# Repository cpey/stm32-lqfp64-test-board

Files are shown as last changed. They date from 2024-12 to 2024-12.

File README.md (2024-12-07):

# STM32 LQFP64 Test Board

A test board designed for STM32 microcontrollers in LQFP64 package. It is intended for use with the STM32F3 and STM32F0 64-pin MCUs, which are mostly pin-to-pin compatbile. The board is programmable via JTAG and SWD using the [STLINK-V3MINIE](https://www.st.com/en/development-tools/stlink-v3minie.html) programmer.

Check out the [schematic](https://github.com/cpey/stm32-lqfp64-test-board/blob/main/stm32_lqfp64_test_board/stm32_lqfp64_test_board.pdf) and the MCU [pin configuration](https://github.com/cpey/stm32-lqfp64-test-board/blob/main/pinout) for more details.

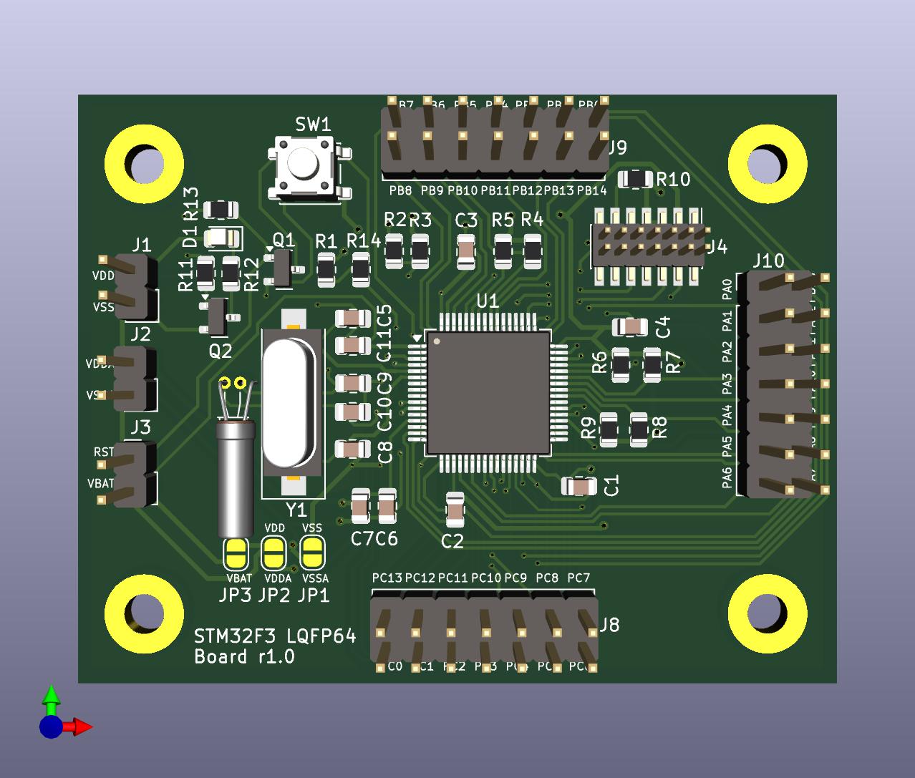
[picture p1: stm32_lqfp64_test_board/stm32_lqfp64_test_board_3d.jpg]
Rendered 3D view of the STM32 LQFP64 test board.


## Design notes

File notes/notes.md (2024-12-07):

# LED resistor calculation

## Collector resistor:

>>> (3.3 - 2) / 20e-3
64.99999999999999

where: 
- 2V is the forward voltage of the LED:
- 20e-3 A is the LED current

## Base resistor:

B -- beta
I_b -- Current base
V_be -- Voltage base-emitter

B = 160
I_b = 20e-3 / 160 = 0.00125 = 1.25 mA 

Voltage Base-Emitter is 0.7V:

R = (3.3 - 0.7) / 1.25e-3 = 2079.9

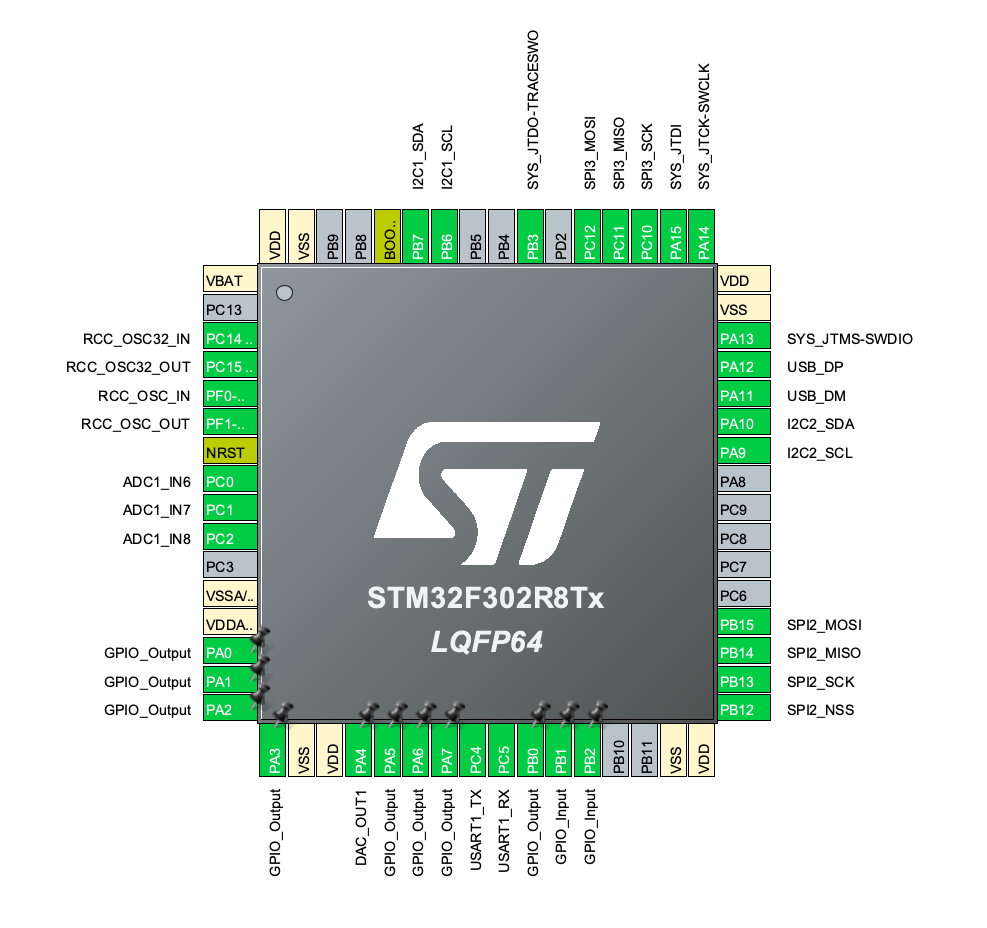
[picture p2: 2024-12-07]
pinout/STM32F302.png

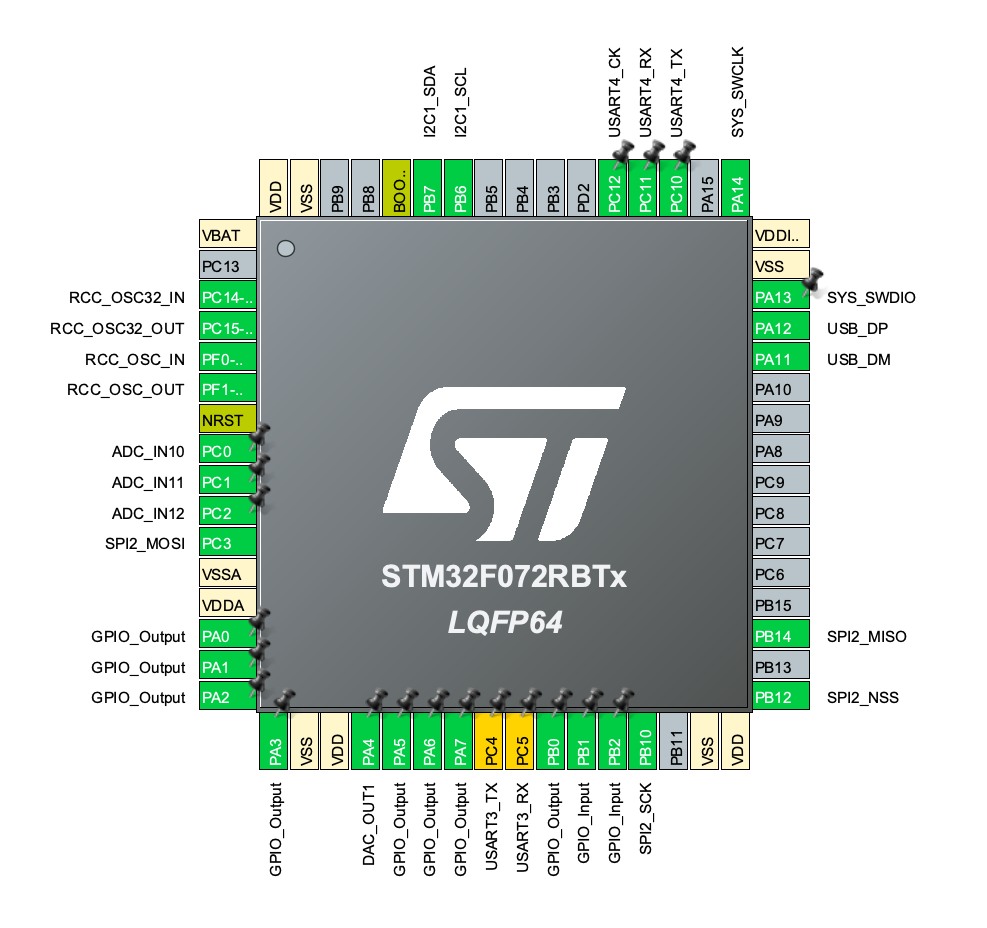
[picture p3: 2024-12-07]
pinout/STM32F072.png

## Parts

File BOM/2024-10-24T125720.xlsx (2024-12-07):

Index | Quantity | Part Number | Manufacturer Part Number | Description | Customer Reference | Available | Backorder | Unit Price | Extended Price USD
1 | 3 | 497-14698-ND | STM32F302R8T6 | IC MCU 32BIT 64KB FLASH 64LQFP |  | 3 | 0 | 6.05 | 18.15
2 | 3 | 497-14644-ND | STM32F072RBT6 | IC MCU 32BIT 128KB FLASH 64LQFP |  | 3 | 0 | 5.72 | 17.16
3 | 3 | 631-1010-1-ND | FC4SDCBMF8.0-T1 | CRYSTAL 8.0000MHZ 20PF SMD |  | 3 | 0 | 0.26 | 0.78
4 | 20 | 478-12776-1-ND | 08055A300JAT2A | CAP CER 30PF 50V C0G/NP0 0805 |  | 20 | 0 | 0.05 | 1.00
5 | 3 | 300-8301-ND | CFS-20632768DZBB | CRYSTAL 32.7680KHZ 6PF TH |  | 3 | 0 | 0.21 | 0.63
6 | 20 | YAG3364CT-ND | RT0805FRE074K7L | RES SMD 4.7K OHM 1% 1/8W 0805 |  | 20 | 0 | 0.03 | 0.60
7 | 20 | 399-C0805C109C5HACAUTOCT-ND | C0805C109C5HACAUTO | CAP CER 0805 1PF 50V ULTRA STABL |  | 20 | 0 | 0.078 | 1.56
8 | 10 | 785-1000-1-ND | AO3400A | MOSFET N-CH 30V 5.7A SOT23-3L |  | 10 | 0 | 0.224 | 2.24
9 | 5 | PTS647SM38SMTR2LFSCT-ND | PTS 647 SM38 SMTR2 LFS | SWITCH TACTILE SPST-NO 0.05A 12V |  | 5 | 0 | 0.26 | 1.30
10 | 20 | RMCF0805FT2K10CT-ND | RMCF0805FT2K10 | RES 2.1K OHM 1% 1/8W 0805 |  | 20 | 0 | 0.021 | 0.42
11 | 10 | 732-4984-1-ND | 150080RS75000 | LED RED CLEAR 0805 SMD |  | 10 | 0 | 0.18 | 1.80
12 | 20 | 311-64.9CRCT-ND | RC0805FR-0764R9L | RES 64.9 OHM 1% 1/8W 0805 |  | 20 | 0 | 0.016 | 0.32
13 | 1 | 497-STLINK-V3MINIE-ND | STLINK-V3MINIE | ST-LINK V3 PROG FOR STM32 |  | 1 | 0 | 11.71 | 11.71
14 | 3 | SAM13170CT-ND | FTSH-107-01-F-DV-K-P-TR | CONN HEADER SMD 14POS 1.27MM |  | 3 | 0 | 2.95 | 8.85
15 | 20 | RMCF0805FT100RCT-ND | RMCF0805FT100R | RES 100 OHM 1% 1/8W 0805 |  | 20 | 0 | 0.021 | 0.42

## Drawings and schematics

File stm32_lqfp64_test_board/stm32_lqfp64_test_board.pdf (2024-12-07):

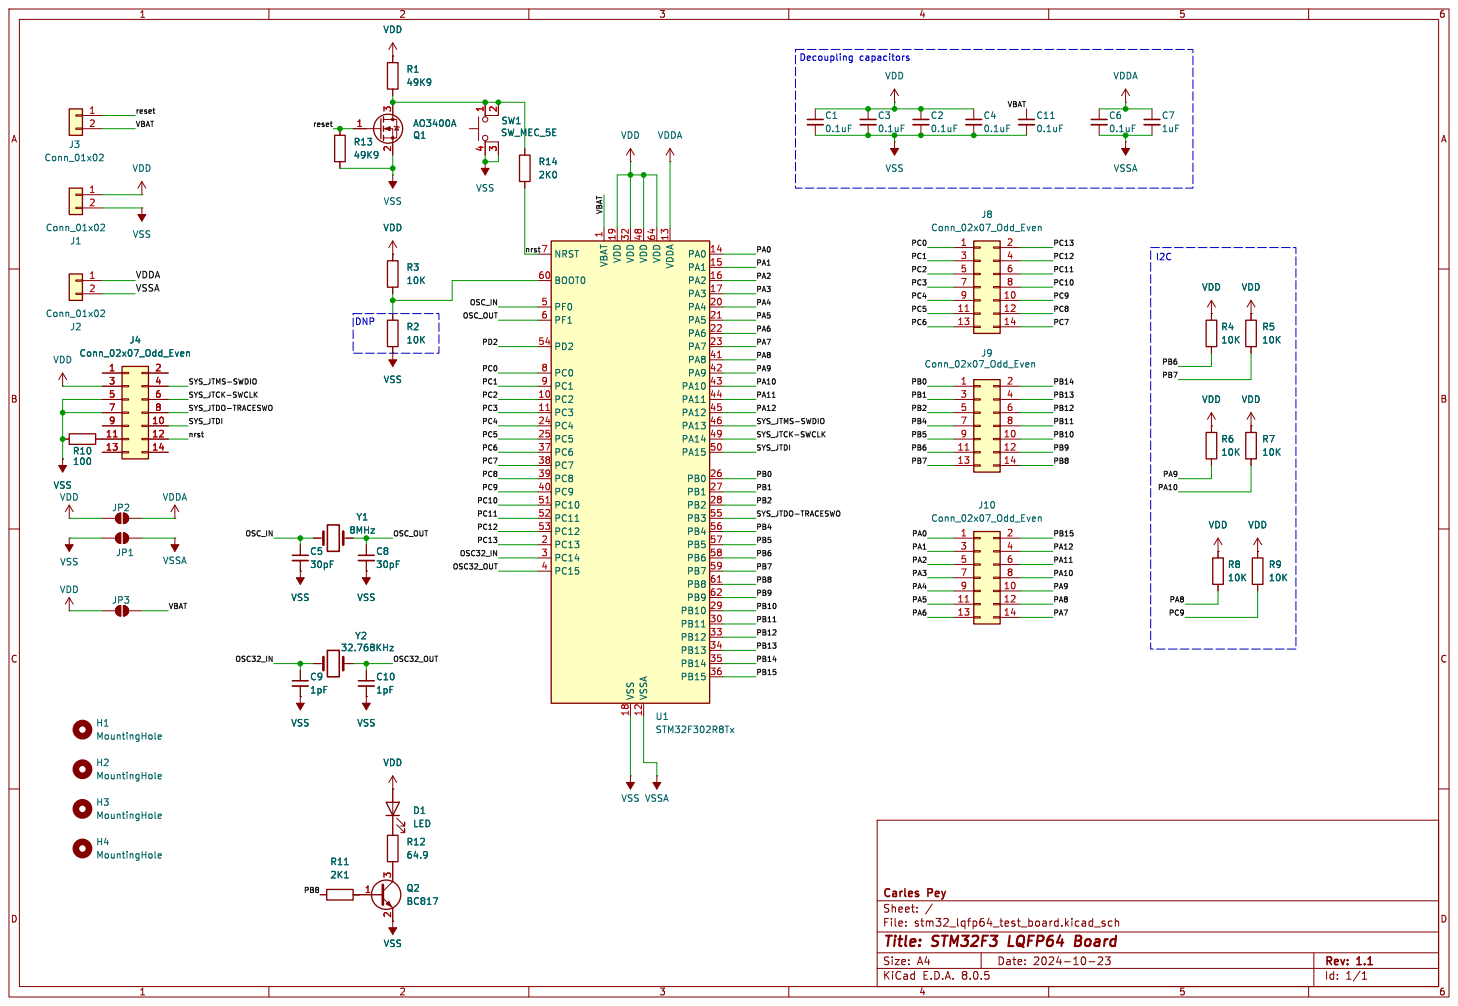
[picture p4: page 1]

1 PC2 10 PC3 11 VSSA 12 VDDA 13 PA0 14 PA1 15 PA2 16 PA3 17 VSS 18 VDD 19 PC13 2 PA4 20 PA5 21 PA6 22 PA7 23 PC4 24 PC5 25 PB0 26 PB1 27 PB2 28 PB10 29 PC14 3 PB11 30 VDD 32 PB12 33 PB13 34 PB14 35 PB15 36 PC6 37 PC7 38 PC8 39 PC15 4 PC9 40 PA8 41 PA9 42 PA10 43 PA11 44 PA12 45 PA13 46 VDD 48 PA14 49 PF0 5 PA15 50 PC10 51 PC11 52 PC12 53 PD2 54 PB3 55 PB4 56 PB5 57 PB6 58 PB7 59 PF1 6 BOOT0 60 PB8 61 PB9 62 VDD 64 NRST 7 PC0 8 PC1 9 U1STM32F302R8Tx

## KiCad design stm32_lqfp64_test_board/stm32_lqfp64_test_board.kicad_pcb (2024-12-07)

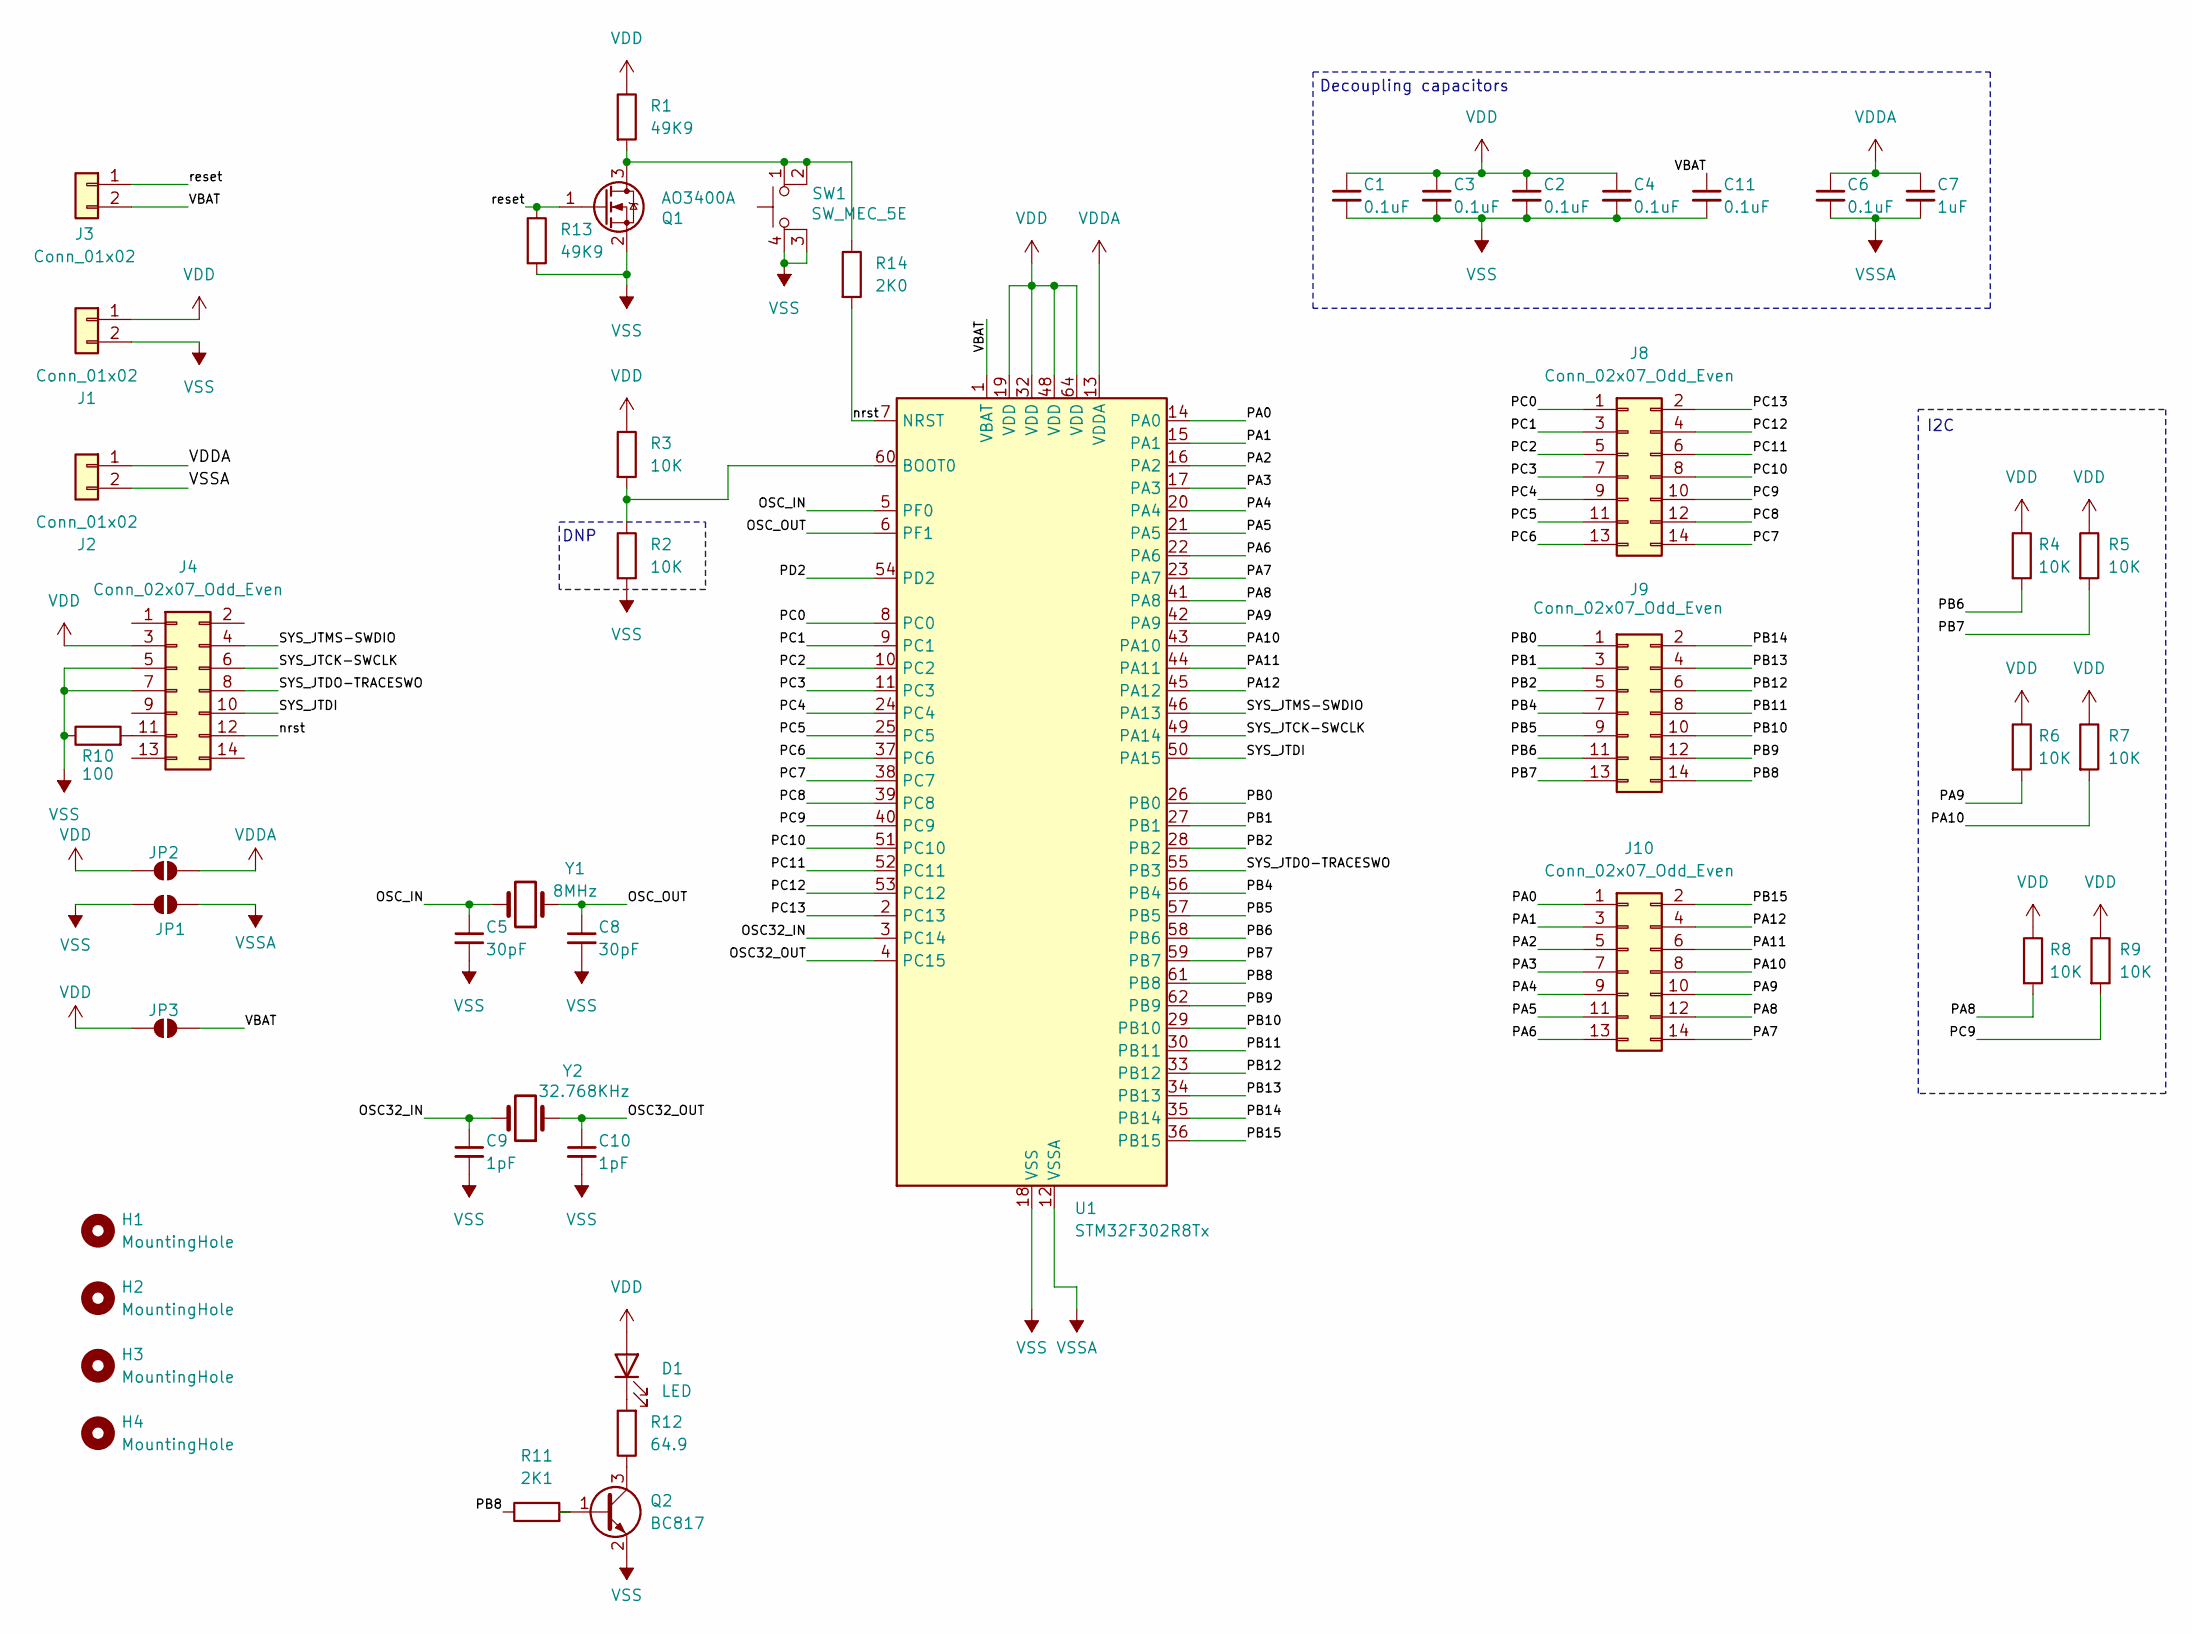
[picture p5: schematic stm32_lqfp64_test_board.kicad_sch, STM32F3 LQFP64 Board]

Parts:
C1, C2, C3, C4, C6, C11: 0.1uF; C_0805_2012Metric
C5, C8: 30pF; C_0805_2012Metric
C7: 1uF; C_0805_2012Metric
C9, C10: 1pF; C_0805_2012Metric
D1: LED; LED_0805_2012Metric
H1, H2, H3, H4: MountingHole; MountingHole_3.2mm_M3_Pad_TopBottom
J1, J2, J3: Conn_01x02; PinHeader_1x02_P2.54mm_Vertical
J4: Conn_02x07_Odd_Even; PinHeader_2x07_P1.27mm_Vertical_SMD
J8, J9, J10: Conn_02x07_Odd_Even; PinHeader_2x07_P2.54mm_Vertical
JP1, JP2, JP3: SolderJumper_2_Open; SolderJumper-2_P1.3mm_Open_RoundedPad1.0x1.5mm
Q1: AO3400A; SOT-23
Q2: BC817; SOT-23
R1, R13: 49K9; R_0805_2012Metric
R2, R3, R4, R5, R6, R7, R8, R9: 10K; R_0805_2012Metric
R10: 100; R_0805_2012Metric
R11: 2K1; R_0805_2012Metric
R12: 64.9; R_0805_2012Metric
R14: 2K0; R_0805_2012Metric
SW1: SW_MEC_5E; SW_SPST_PTS647_Sx38_2
U1: STM32F302R8Tx; LQFP-64_10x10mm_P0.5mm
Y1: 8MHz; Crystal_SMD_HC49-SD_FOX_FC4SD
Y2: 32.768KHz; Crystal_AT310_D2.4mm_L6.0mm_Horizontal_CFS-206

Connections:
/OSC32_IN: C9.1, U1.3 (PC14), Y2.2
/OSC32_OUT: C10.1, U1.4 (PC15), Y2.1
/OSC_IN: C5.1, U1.5 (PF0), Y1.2
/OSC_OUT: C8.1, U1.6 (PF1), Y1.1
/PA0: J10.1, U1.14 (PA0)
/PA1: J10.3, U1.15 (PA1)
/PA2: J10.5, U1.16 (PA2)
/PA3: J10.7, U1.17 (PA3)
/PA4: J10.9, U1.20 (PA4)
/PA5: J10.11, U1.21 (PA5)
/PA6: J10.13, U1.22 (PA6)
/PA7: J10.14, U1.23 (PA7)
/PA8: J10.12, R8.2, U1.41 (PA8)
/PA9: J10.10, R6.2, U1.42 (PA9)
/PA10: J10.8, R7.2, U1.43 (PA10)
/PA11: J10.6, U1.44 (PA11)
/PA12: J10.4, U1.45 (PA12)
/PB0: J9.1, U1.26 (PB0)
/PB1: J9.3, U1.27 (PB1)
/PB2: J9.5, U1.28 (PB2)
/PB4: J9.7, U1.56 (PB4)
/PB5: J9.9, U1.57 (PB5)
/PB6: J9.11, R4.2, U1.58 (PB6)
/PB7: J9.13, R5.2, U1.59 (PB7)
/PB8: J9.14, R11.1, U1.61 (PB8)
/PB9: J9.12, U1.62 (PB9)
/PB10: J9.10, U1.29 (PB10)
/PB11: J9.8, U1.30 (PB11)
/PB12: J9.6, U1.33 (PB12)
/PB13: J9.4, U1.34 (PB13)
/PB14: J9.2, U1.35 (PB14)
/PB15: J10.2, U1.36 (PB15)
/PC0: J8.1, U1.8 (PC0)
/PC1: J8.3, U1.9 (PC1)
/PC2: J8.5, U1.10 (PC2)
/PC3: J8.7, U1.11 (PC3)
/PC4: J8.9, U1.24 (PC4)
/PC5: J8.11, U1.25 (PC5)
/PC6: J8.13, U1.37 (PC6)
/PC7: J8.14, U1.38 (PC7)
/PC8: J8.12, U1.39 (PC8)
/PC9: J8.10, R9.2, U1.40 (PC9)
/PC10: J8.8, U1.51 (PC10)
/PC11: J8.6, U1.52 (PC11)
/PC12: J8.4, U1.53 (PC12)
/PC13: J8.2, U1.2 (PC13)
/PD2: U1.54 (PD2)
/SYS_JTCK-SWCLK: J4.6, U1.49 (PA14)
/SYS_JTDI: J4.10, U1.50 (PA15)
/SYS_JTDO-TRACESWO: J4.8, U1.55 (PB3)
/SYS_JTMS-SWDIO: J4.4, U1.46 (PA13)
/VBAT: C11.1, J3.2, JP3.1 (A), U1.1 (VBAT)
/nrst: J4.12, R14.2, U1.7 (NRST)
/reset: J3.1, Q1.1 (G), R13.1
unnamed: D1.1 (K), R12.2
unnamed: J4.11, R10.2
unnamed: Q1.3 (D), R1.2, R14.1, SW1.1, SW1.2
unnamed: Q2.1 (B), R11.2
unnamed: Q2.3 (C), R12.1
unnamed: R2.1, R3.2, U1.60 (BOOT0)
VDD: C1.1, C2.1, C3.1, C4.1, D1.2 (A), J1.1, J4.3, JP2.2 (B), JP3.2 (B), R1.1, R3.1, R4.1, R5.1, R6.1, R7.1, R8.1, R9.1, U1.19 (VDD), U1.32 (VDD), U1.48 (VDD), U1.64 (VDD)
VDDA: C6.1, C7.1, J2.1, JP2.1 (A), U1.13 (VDDA)
VSS: C1.2, C2.2, C3.2, C4.2, C5.2, C8.2, C9.2, C10.2, C11.2, J1.2, J4.5, J4.7, JP1.2 (B), Q1.2 (S), Q2.2 (E), R2.2, R10.1, R13.2, SW1.3 (K), SW1.4 (A), U1.18 (VSS), U1.31 (VSS), U1.47 (VSS), U1.63 (VSS)
VSSA: C6.2, C7.2, J2.2, JP1.1 (A), U1.12 (VSSA)

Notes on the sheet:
Decoupling capacitors
I2C
DNP

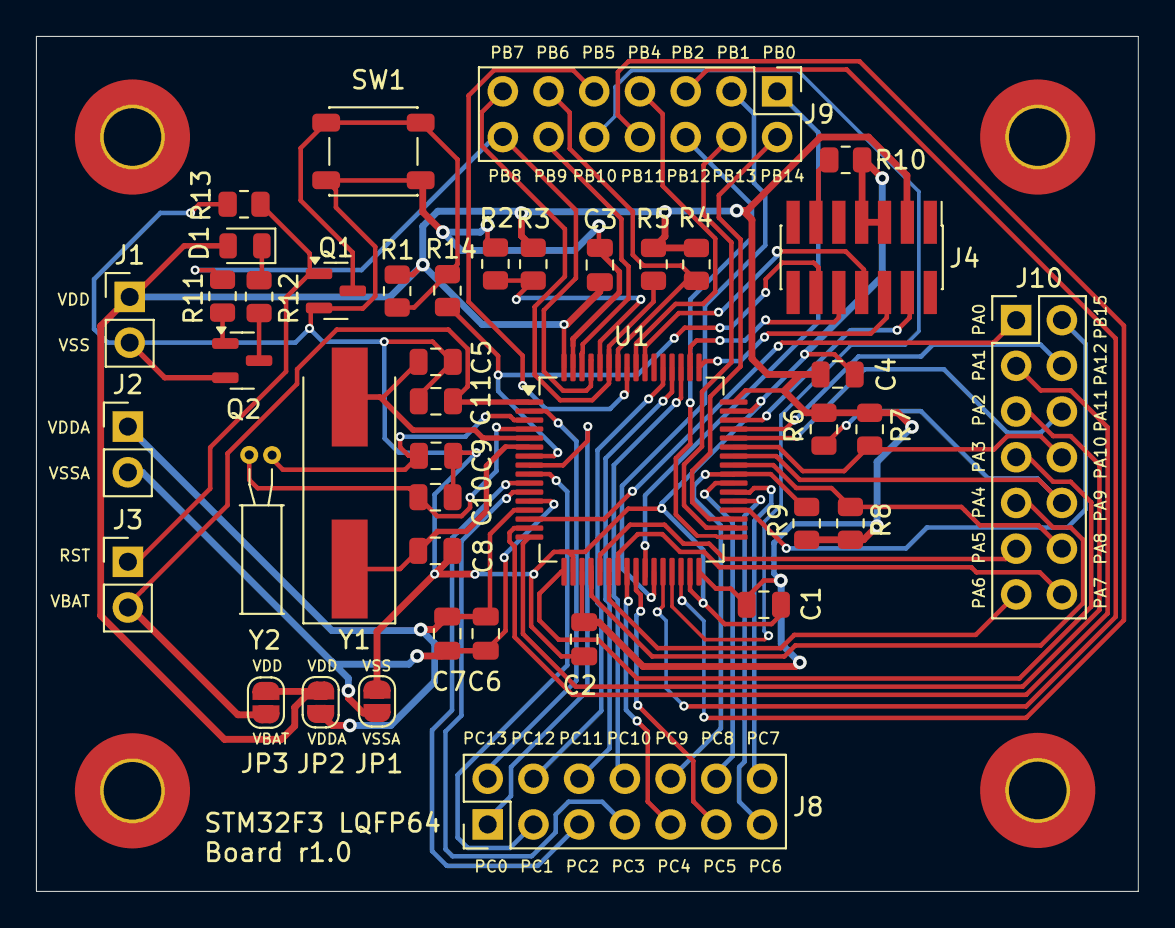
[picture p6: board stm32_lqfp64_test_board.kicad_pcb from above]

Board: 2 copper layers, 61.2 x 47.5 mm, 46 parts (0 on the bottom side), 63 nets.
